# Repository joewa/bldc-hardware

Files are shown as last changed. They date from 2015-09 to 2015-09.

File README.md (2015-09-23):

bldc-hardware
=============



This the Hardware for my open source custom ESC. This is a forked repository from mrkindustries, who made many improvements to my original hardware design.

Here is a BOM on google drive that I try to keep up to date:
https://docs.google.com/spreadsheet/ccc?key=0AnvZ-ouEB058dGpzaDl4MUxNM3NxZ1BzTWNZZ1RhRUE&usp=sharing

Have a look at this post for a tutorial on how to get started:
http://vedder.se/2015/01/vesc-open-source-esc/

VESC Hardware is licensed under the Creative Commons Attribution-ShareAlike 4.0 International License. To view a copy of this license, visit http://creativecommons.org/licenses/by-sa/4.0/.

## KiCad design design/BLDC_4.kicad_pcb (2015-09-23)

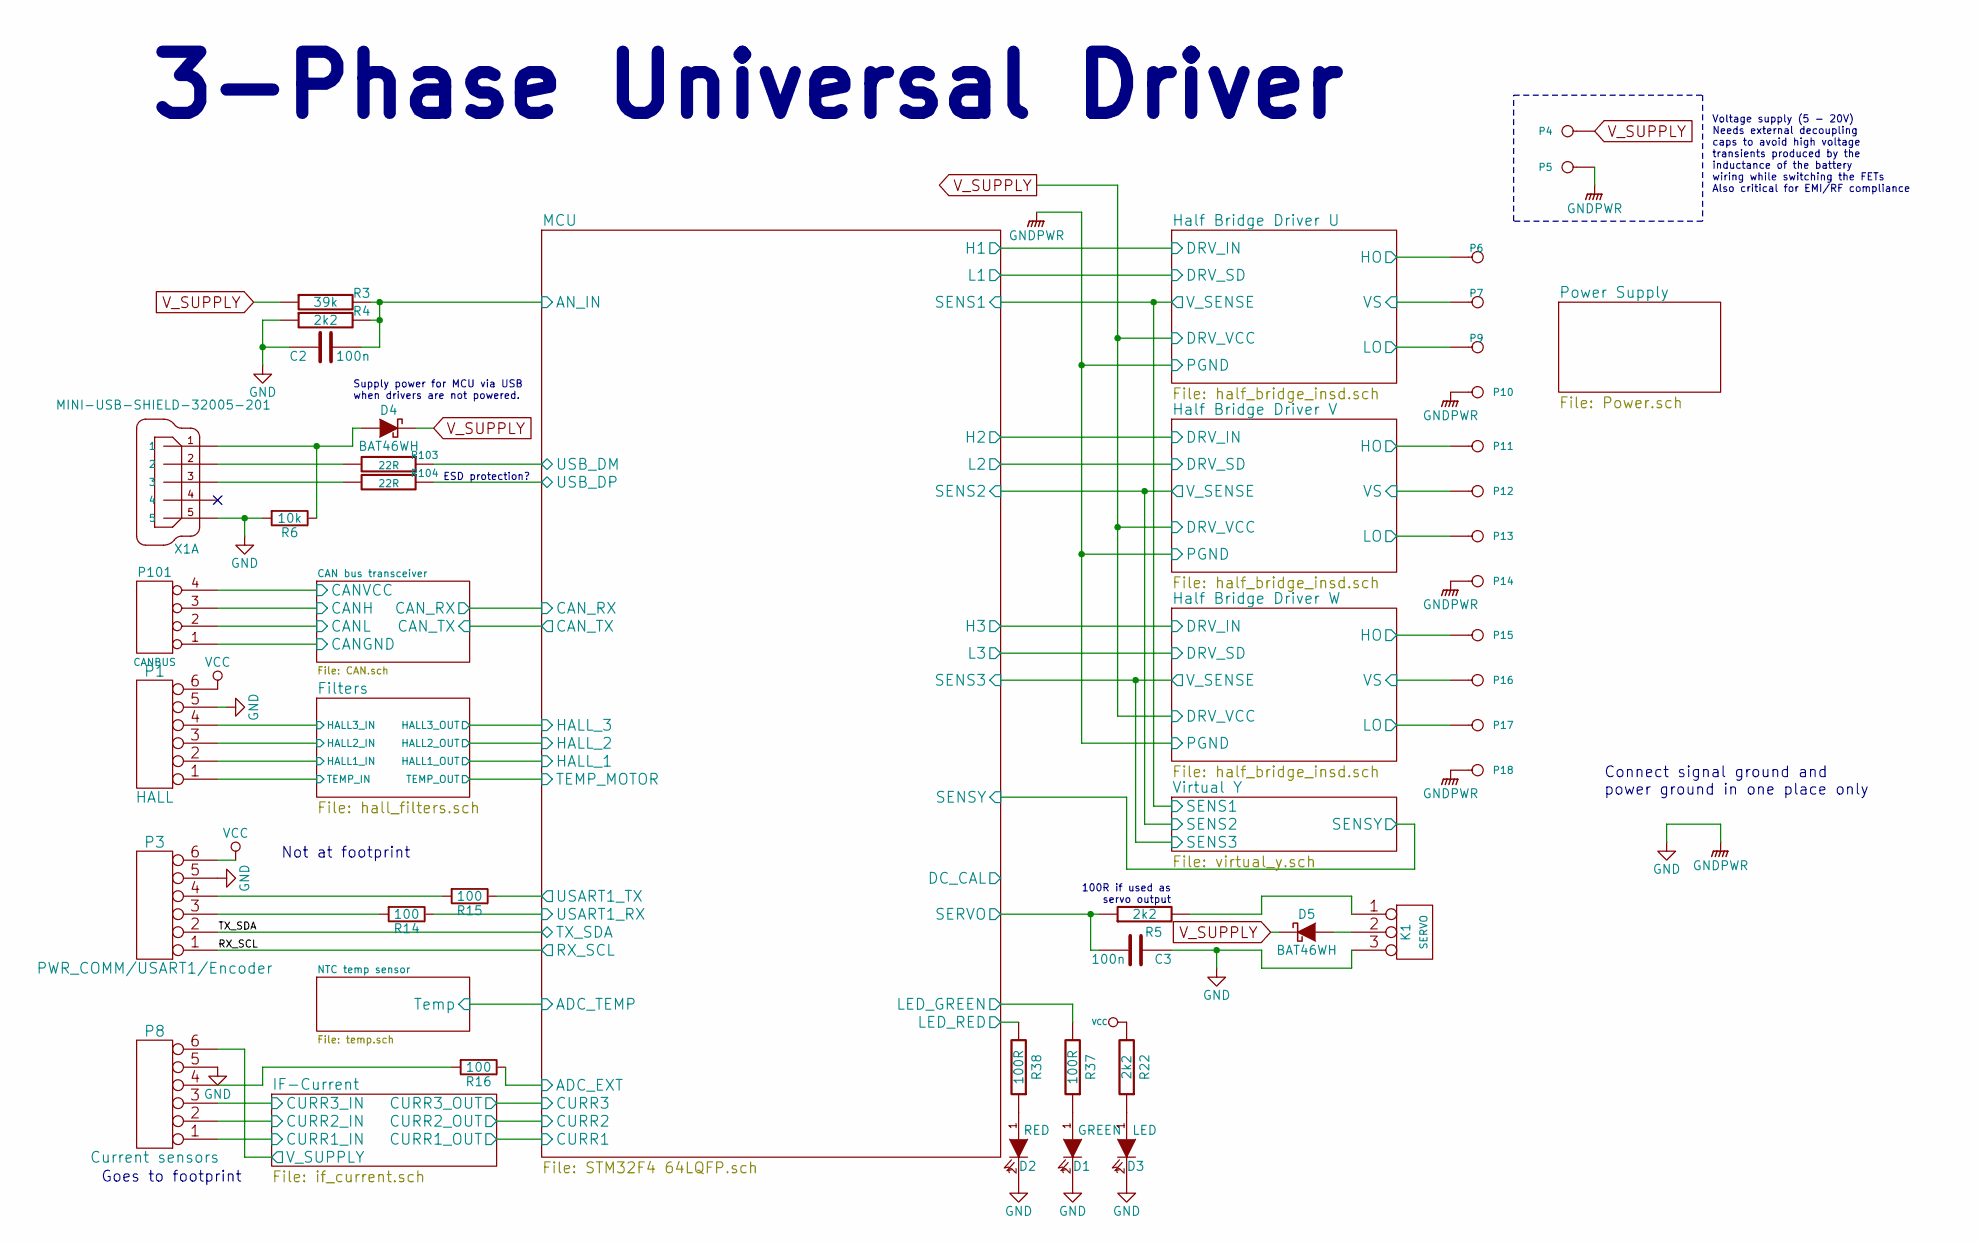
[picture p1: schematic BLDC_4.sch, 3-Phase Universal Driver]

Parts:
C2, C3: 100n; C_0603
D1: GREEN; LED-0603
D2: RED; LED-0603
D3: LED; LED-0603
D4, D5: BAT46WH; SOD-123
K1: SERVO; pinhead-1X03
P1: HALL; MICRO_JST_6
P3: PWR_COMM/USART1/Encoder; MICRO_JST_6
P4: IN+; 1PAD_4x5mm
P5: IN-; 1PAD_4x5mm
P6, P7: CONN_DRV; 1PAD_4x5mm
P8: Current sensors; MICRO_JST_6
P9, P10, P11, P12, P13, P14, P15, P16, P17, P18: CONN_DRV; PAD_DRV
P101: CANBUS; pinhead-1X03
R3: 39k; R_0603_HandSoldering
R4, R5, R22: 2k2; R_0603_HandSoldering
R6: 10k; R_0603
R14, R15, R16: 100; R_0603
R37, R38: 100R; R_0603
R103, R104: 22R; R_0603
X1: MINI-USB-SHIELD-32005-201; con-cypressindustries-32005-201

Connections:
/CAN bus transceiver/CANGND: P101.1; also elsewhere on the board
/CAN bus transceiver/CANH: P101.3; also elsewhere on the board
/CAN bus transceiver/CANL: P101.2; also elsewhere on the board
/Filters/HALL1_IN: P1.2; also elsewhere on the board
/Filters/HALL2_IN: P1.3; also elsewhere on the board
/Filters/HALL3_IN: P1.4; also elsewhere on the board
/Filters/TEMP_IN: P1.1; also elsewhere on the board
/Half Bridge Driver U/HO: P6.1; also elsewhere on the board
/Half Bridge Driver U/LO: P9.1; also elsewhere on the board
/Half Bridge Driver U/VS: P7.1; also elsewhere on the board
/Half Bridge Driver V/HO: P11.1; also elsewhere on the board
/Half Bridge Driver V/LO: P13.1; also elsewhere on the board
/Half Bridge Driver V/VS: P12.1; also elsewhere on the board
/Half Bridge Driver W/HO: P15.1; also elsewhere on the board
/Half Bridge Driver W/LO: P17.1; also elsewhere on the board
/Half Bridge Driver W/VS: P16.1; also elsewhere on the board
/IF-Current/CURR1_IN: P8.1; also elsewhere on the board
/IF-Current/CURR2_IN: P8.2; also elsewhere on the board
/IF-Current/CURR3_IN: P8.3; also elsewhere on the board
/IF-Current/V_SUPPLY: P8.6; also elsewhere on the board
/MCU/ADC_EXT: R16.1; also elsewhere on the board
/MCU/AN_IN: C2.2, R3.2, R4.2; also elsewhere on the board
/MCU/LED_GREEN: R37.2; also elsewhere on the board
/MCU/LED_RED: R38.2; also elsewhere on the board
/MCU/RX_SCL: P3.1; also elsewhere on the board
/MCU/SERVO: C3.2, R5.1; also elsewhere on the board
/MCU/TX_SDA: P3.2; also elsewhere on the board
/MCU/USART1_RX: R14.1; also elsewhere on the board
/MCU/USART1_TX: R15.1; also elsewhere on the board
/MCU/USB_DM: R103.1; also elsewhere on the board
/MCU/USB_DP: R104.1; also elsewhere on the board
GND: C2.1, C3.1, D1.2 (K), D2.2 (K), D3.2 (K), K1.3, P1.5, P3.5, P5.1, P8.5, P10.1, P14.1, P18.1, R4.1, R6.2, X1.5; also elsewhere on the board
unnamed: D1.1 (A), R37.1
unnamed: D2.1 (A), R38.1
unnamed: D3.1 (A), R22.1
unnamed: D4.2 (A), R6.1, X1.1
unnamed: D5.2 (A), K1.2 (PM)
unnamed: K1.1, R5.2
unnamed: P3.3, R14.2
unnamed: P3.4, R15.2
unnamed: P8.4, R16.2
unnamed: R103.2, X1.2
unnamed: R104.2, X1.3
VCC: P1.6, P3.6, R22.2; also elsewhere on the board
V_SUPPLY: D4.1 (K), D5.1 (K), P4.1, R3.1; also elsewhere on the board

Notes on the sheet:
100R if used as servo output
Supply power for MCU via USB when drivers are not powered.
ESD protection?
3-Phase Universal Driver
Voltage supply (5 - 20V) Needs external decoupling caps to avoid high voltage transients produced by the inductance of the battery wiring while switching the FETs Also critical for EMI/RF compliance
Connect signal ground and power ground in one place only
Not at footprint
Goes to footprint

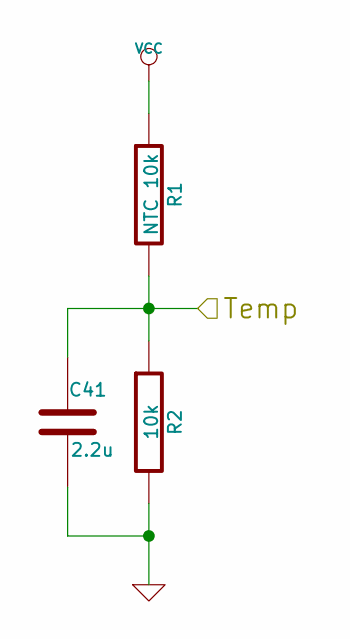
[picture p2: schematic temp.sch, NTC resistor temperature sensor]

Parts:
C41: 2.2u; C_0603
R1: NTC 10k; R_0603_HandSoldering
R2: 10k; R_0603_HandSoldering

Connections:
/MCU/ADC_TEMP: C41.1, R1.2, R2.1; also elsewhere on the board
GND: C41.2, R2.2; also elsewhere on the board
VCC: R1.1; also elsewhere on the board

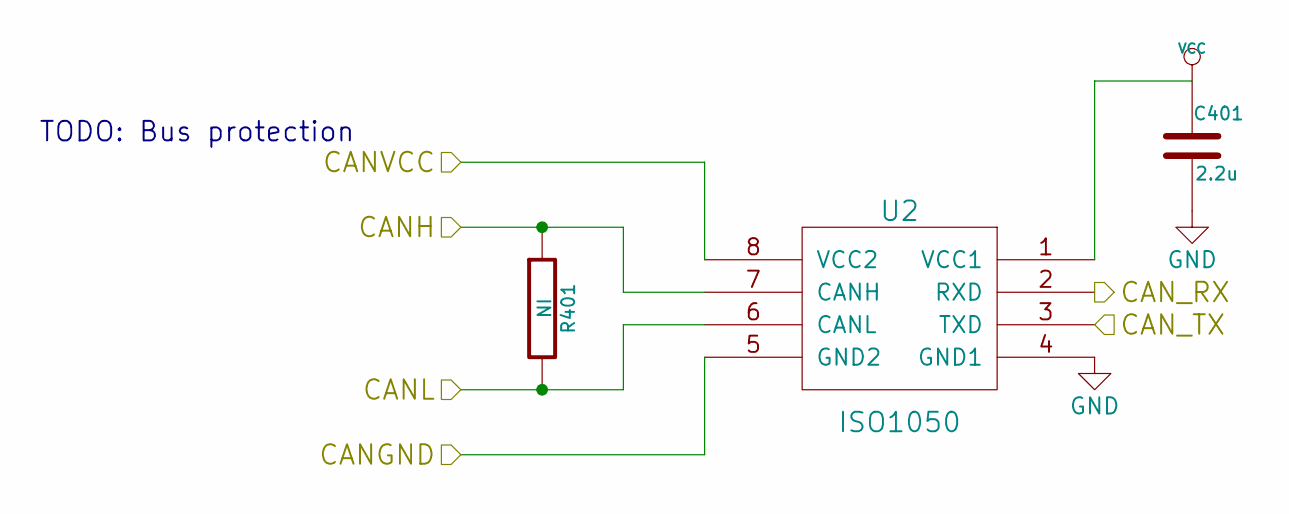
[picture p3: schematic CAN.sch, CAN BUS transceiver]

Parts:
C401: 2.2u; C_0603
R401: NI; R_0603_HandSoldering
U2: ISO1050; PDSO-G8

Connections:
/CAN bus transceiver/CANGND: U2.5 (GND2); also elsewhere on the board
/CAN bus transceiver/CANH: R401.1, U2.7 (CANH); also elsewhere on the board
/CAN bus transceiver/CANL: R401.2, U2.6 (CANL); also elsewhere on the board
/CAN bus transceiver/CAN_RX: U2.2 (RXD); also elsewhere on the board
/CAN bus transceiver/CAN_TX: U2.3 (TXD); also elsewhere on the board
GND: C401.2, U2.4 (GND1); also elsewhere on the board
VCC: C401.1, U2.1 (VCC1); also elsewhere on the board

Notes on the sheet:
TODO: Bus protection

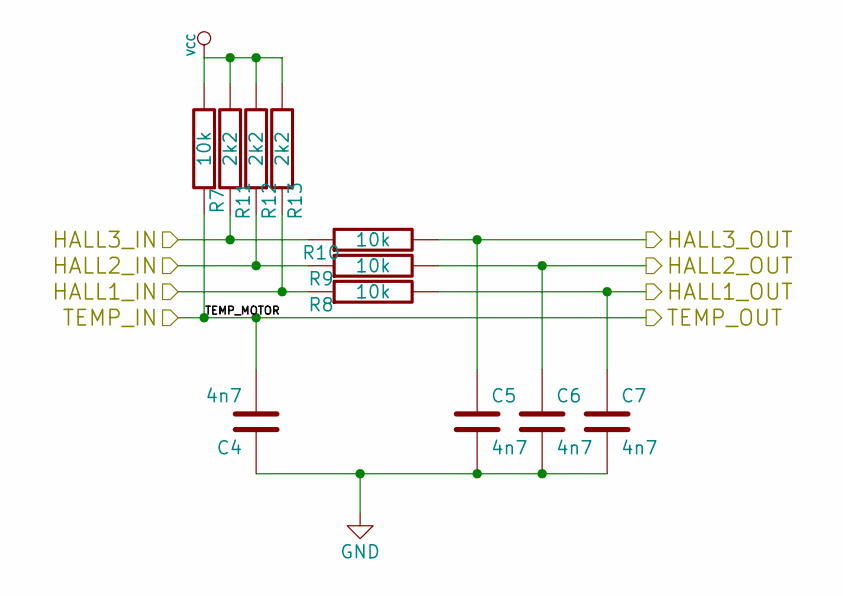
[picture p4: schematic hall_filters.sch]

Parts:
C4, C5, C6, C7: 4n7; C_0603
R7, R8, R9, R10: 10k; R_0603
R11, R12, R13: 2k2; R_0603

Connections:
/Filters/HALL1_IN: R8.1, R13.1; also elsewhere on the board
/Filters/HALL1_OUT: C7.1, R8.2; also elsewhere on the board
/Filters/HALL2_IN: R9.1, R12.1; also elsewhere on the board
/Filters/HALL2_OUT: C6.1, R9.2; also elsewhere on the board
/Filters/HALL3_IN: R10.1, R11.1; also elsewhere on the board
/Filters/HALL3_OUT: C5.1, R10.2; also elsewhere on the board
/Filters/TEMP_IN: C4.2, R7.1; also elsewhere on the board
GND: C4.1, C5.2, C6.2, C7.2; also elsewhere on the board
VCC: R7.2, R11.2, R12.2, R13.2; also elsewhere on the board

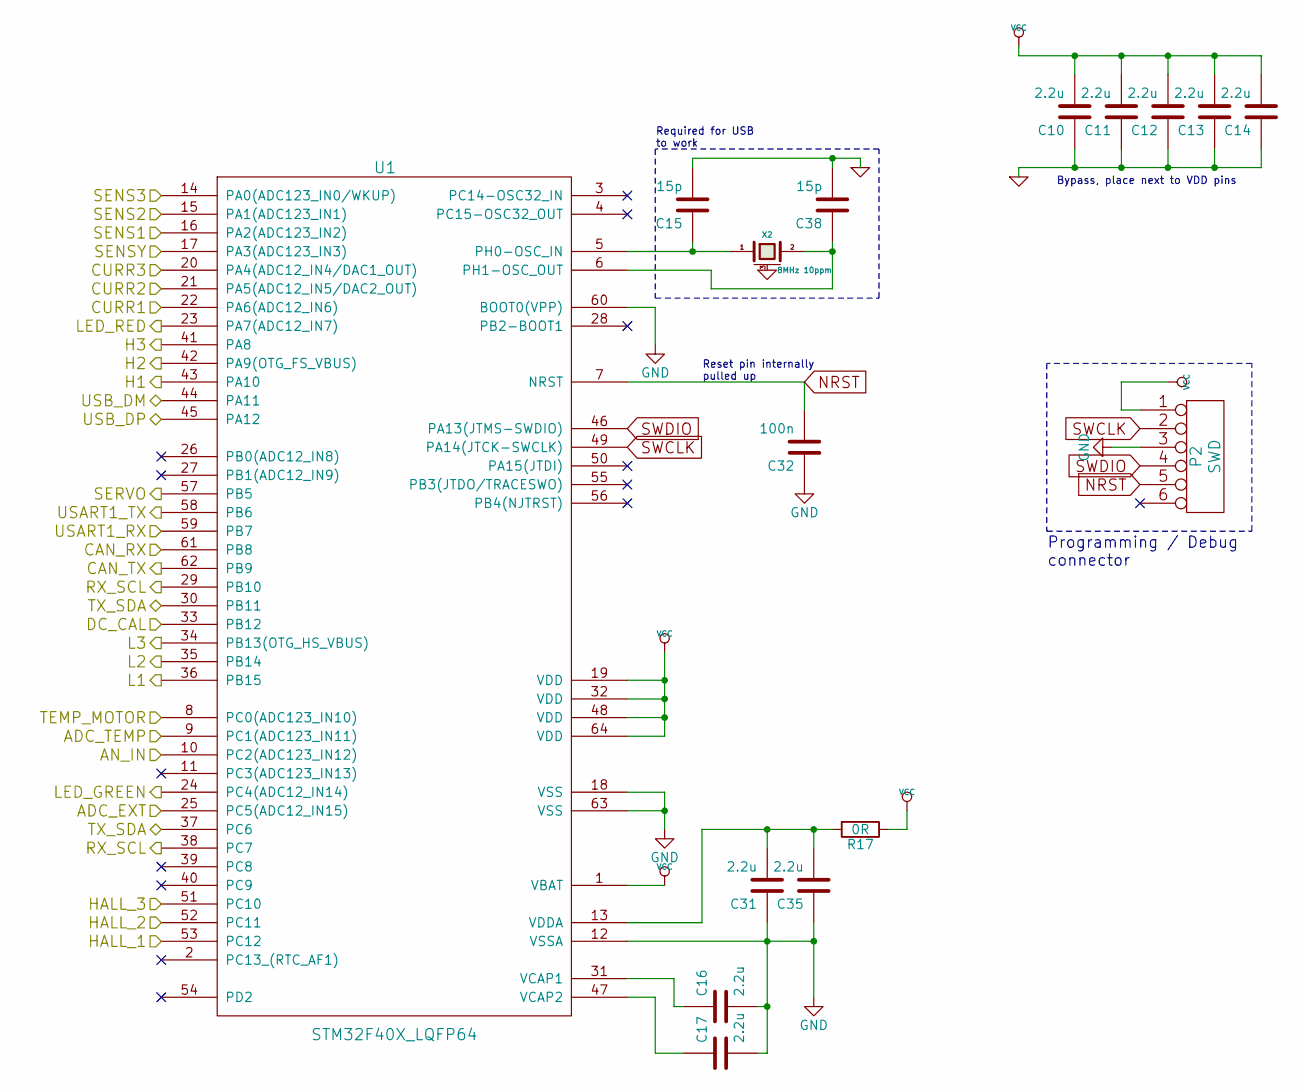
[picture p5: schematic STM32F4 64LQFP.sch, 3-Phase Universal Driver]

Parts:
C10, C11, C12, C13, C14, C16, C17, C31, C35: 2.2u; C_0603
C15, C38: 15p; C_0603
C32: 100n; C_0603
P2: SWD; MICRO_JST_6
R17: 0R; R_0603_HandSoldering
U1: STM32F40X_LQFP64; lqfp64_pad_mod
X2: 8MHz 10ppm; Crystal_5x3mm; mfg# ABM3B-8.0-10-1UT

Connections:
/CAN bus transceiver/CAN_RX: U1.61 (PB8); also elsewhere on the board
/CAN bus transceiver/CAN_TX: U1.62 (PB9); also elsewhere on the board
/Filters/HALL1_OUT: U1.53 (PC12); also elsewhere on the board
/Filters/HALL2_OUT: U1.52 (PC11); also elsewhere on the board
/Filters/HALL3_OUT: U1.51 (PC10); also elsewhere on the board
/Filters/TEMP_IN: U1.8 (PC0(ADC123_IN10)); also elsewhere on the board
/Half Bridge Driver U/DRV_IN: U1.43 (PA10); also elsewhere on the board
/Half Bridge Driver U/DRV_SD: U1.36 (PB15); also elsewhere on the board
/Half Bridge Driver V/DRV_IN: U1.42 (PA9(OTG_FS_VBUS)); also elsewhere on the board
/Half Bridge Driver V/DRV_SD: U1.35 (PB14); also elsewhere on the board
/Half Bridge Driver W/DRV_IN: U1.41 (PA8); also elsewhere on the board
/Half Bridge Driver W/DRV_SD: U1.34 (PB13(OTG_HS_VBUS)); also elsewhere on the board
/MCU/ADC_EXT: U1.25 (PC5(ADC12_IN15)); also elsewhere on the board
/MCU/ADC_TEMP: U1.9 (PC1(ADC123_IN11)); also elsewhere on the board
/MCU/AN_IN: U1.10 (PC2(ADC123_IN12)); also elsewhere on the board
/MCU/CURR1: U1.22 (PA6(ADC12_IN6)); also elsewhere on the board
/MCU/CURR2: U1.21 (PA5(ADC12_IN5/DAC2_OUT)); also elsewhere on the board
/MCU/CURR3: U1.20 (PA4(ADC12_IN4/DAC1_OUT)); also elsewhere on the board
/MCU/LED_GREEN: U1.24 (PC4(ADC12_IN14)); also elsewhere on the board
/MCU/LED_RED: U1.23 (PA7(ADC12_IN7)); also elsewhere on the board
/MCU/RX_SCL: U1.29 (PB10), U1.38 (PC7); also elsewhere on the board
/MCU/SENS1: U1.16 (PA2(ADC123_IN2)); also elsewhere on the board
/MCU/SENS2: U1.15 (PA1(ADC123_IN1)); also elsewhere on the board
/MCU/SENS3: U1.14 (PA0(ADC123_IN0/WKUP)); also elsewhere on the board
/MCU/SENSY: U1.17 (PA3(ADC123_IN3)); also elsewhere on the board
/MCU/SERVO: U1.57 (PB5); also elsewhere on the board
/MCU/TX_SDA: U1.30 (PB11), U1.37 (PC6); also elsewhere on the board
/MCU/USART1_RX: U1.59 (PB7); also elsewhere on the board
/MCU/USART1_TX: U1.58 (PB6); also elsewhere on the board
/MCU/USB_DM: U1.44 (PA11); also elsewhere on the board
/MCU/USB_DP: U1.45 (PA12); also elsewhere on the board
GND: C10.1, C11.1, C12.1, C13.1, C14.1, C15.2, C16.2, C17.2, C31.1, C32.1, C35.1, C38.2, P2.3, U1.12 (VSSA), U1.18 (VSS), U1.60 (BOOT0(VPP)), U1.63 (VSS), X2.3 (case); also elsewhere on the board
NRST: C32.2, P2.5, U1.7 (NRST)
unnamed: C15.1, U1.5 (PH0-OSC_IN), X2.1
unnamed: C16.1, U1.31 (VCAP1)
unnamed: C17.1, U1.47 (VCAP2)
unnamed: C31.2, C35.2, R17.2, U1.13 (VDDA)
unnamed: C38.1, U1.6 (PH1-OSC_OUT), X2.2
SWCLK: P2.2, U1.49 (PA14(JTCK-SWCLK))
SWDIO: P2.4, U1.46 (PA13(JTMS-SWDIO))
VCC: C10.2, C11.2, C12.2, C13.2, C14.2, P2.1, R17.1, U1.1 (VBAT), U1.19 (VDD), U1.32 (VDD), U1.48 (VDD), U1.64 (VDD); also elsewhere on the board

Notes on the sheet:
Programming / Debug connector
Reset pin internally pulled up
Required for USB to work
Bypass, place next to VDD pins

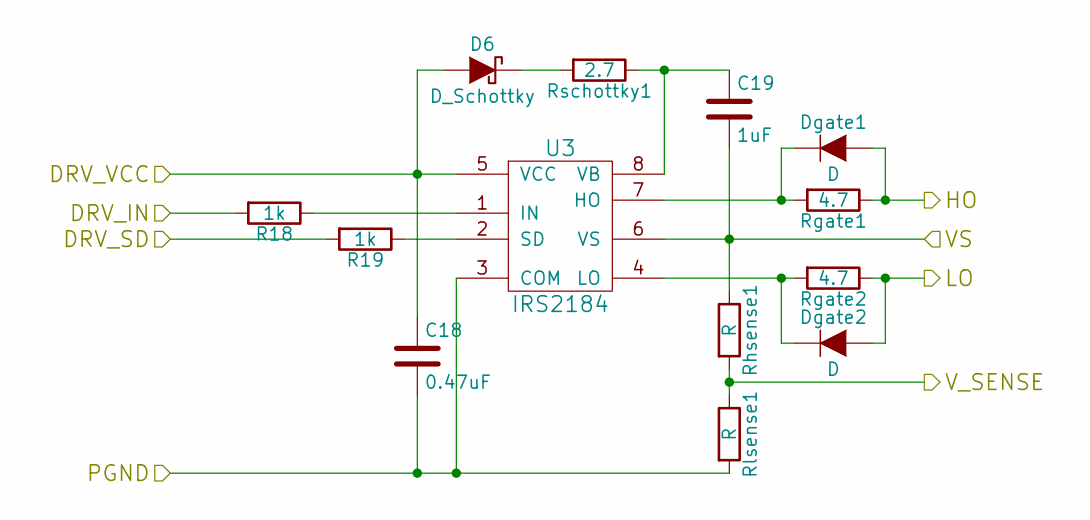
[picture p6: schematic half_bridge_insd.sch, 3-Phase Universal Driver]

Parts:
C18: 0.47uF; C_0805_HandSoldering
C19: 1uF; C_1210_HandSoldering
D6: D_Schottky; DO-214AC_SOD-123
Dgate1, Dgate2: D; SOD-123
R18, R19: 1k; R_0603
Rgate1, Rgate2: 4.7; R_0805_HandSoldering
Rhsense1: R; R_0805_HandSoldering
Rlsense1: R; R_0603_HandSoldering
Rschottky1: 2.7; R_0805_HandSoldering
U3: IRS2184; SOIC-8_3.9x4.9mm_Pitch1.27mm

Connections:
/Half Bridge Driver U/DRV_IN: R18.2; also elsewhere on the board
/Half Bridge Driver U/DRV_SD: R19.2; also elsewhere on the board
/Half Bridge Driver U/HO: Dgate1.2 (A), Rgate1.1; also elsewhere on the board
/Half Bridge Driver U/LO: Dgate2.2 (A), Rgate2.1; also elsewhere on the board
/Half Bridge Driver U/VS: C19.2, Rhsense1.1, U3.6 (VS); also elsewhere on the board
/MCU/SENS1: Rhsense1.2, Rlsense1.1; also elsewhere on the board
GND: C18.2, Rlsense1.2, U3.3 (COM); also elsewhere on the board
unnamed: C19.1, Rschottky1.1, U3.8 (VB)
unnamed: D6.1 (K), Rschottky1.2
unnamed: Dgate1.1 (K), Rgate1.2, U3.7 (HO)
unnamed: Dgate2.1 (K), Rgate2.2, U3.4 (LO)
unnamed: R18.1, U3.1 (IN)
unnamed: R19.1, U3.2 (SD)
V_SUPPLY: C18.1, D6.2 (A), U3.5 (VCC); also elsewhere on the board

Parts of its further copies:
C20, C22: 0.47uF; C_0805_HandSoldering
C21, C23: 1uF; C_1210_HandSoldering
D7, D8: D_Schottky; DO-214AC_SOD-123
Dgate3, Dgate4, Dgate5, Dgate6: D; SOD-123
R20, R21, R23, R24: 1k; R_0603
Rgate3, Rgate4, Rgate5, Rgate6: 4.7; R_0805_HandSoldering
Rhsense2, Rhsense3: R; R_0805_HandSoldering
Rlsense2, Rlsense3: R; R_0603_HandSoldering
Rschottky2, Rschottky3: 2.7; R_0805_HandSoldering
U4, U5: IRS2184; SOIC-8_3.9x4.9mm_Pitch1.27mm

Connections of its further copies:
/Half Bridge Driver V/DRV_IN: R20.2; also elsewhere on the board
/Half Bridge Driver V/DRV_SD: R21.2; also elsewhere on the board
/Half Bridge Driver V/HO: Dgate3.2 (A), Rgate3.1; also elsewhere on the board
/Half Bridge Driver V/LO: Dgate4.2 (A), Rgate4.1; also elsewhere on the board
/Half Bridge Driver V/VS: C21.2, Rhsense2.1, U4.6 (VS); also elsewhere on the board
/Half Bridge Driver W/DRV_IN: R23.2; also elsewhere on the board
/Half Bridge Driver W/DRV_SD: R24.2; also elsewhere on the board
/Half Bridge Driver W/HO: Dgate5.2 (A), Rgate5.1; also elsewhere on the board
/Half Bridge Driver W/LO: Dgate6.2 (A), Rgate6.1; also elsewhere on the board
/Half Bridge Driver W/VS: C23.2, Rhsense3.1, U5.6 (VS); also elsewhere on the board
/MCU/SENS2: Rhsense2.2, Rlsense2.1; also elsewhere on the board
/MCU/SENS3: Rhsense3.2, Rlsense3.1; also elsewhere on the board
GND: C20.2, C22.2, Rlsense2.2, Rlsense3.2, U4.3 (COM), U5.3 (COM); also elsewhere on the board
unnamed: C21.1, Rschottky2.1, U4.8 (VB)
unnamed: C23.1, Rschottky3.1, U5.8 (VB)
unnamed: D7.1 (K), Rschottky2.2
unnamed: D8.1 (K), Rschottky3.2
unnamed: Dgate3.1 (K), Rgate3.2, U4.7 (HO)
unnamed: Dgate4.1 (K), Rgate4.2, U4.4 (LO)
unnamed: Dgate5.1 (K), Rgate5.2, U5.7 (HO)
unnamed: Dgate6.1 (K), Rgate6.2, U5.4 (LO)
unnamed: R20.1, U4.1 (IN)
unnamed: R21.1, U4.2 (SD)
unnamed: R23.1, U5.1 (IN)
unnamed: R24.1, U5.2 (SD)
V_SUPPLY: C20.1, C22.1, D7.2 (A), D8.2 (A), U4.5 (VCC), U5.5 (VCC); also elsewhere on the board

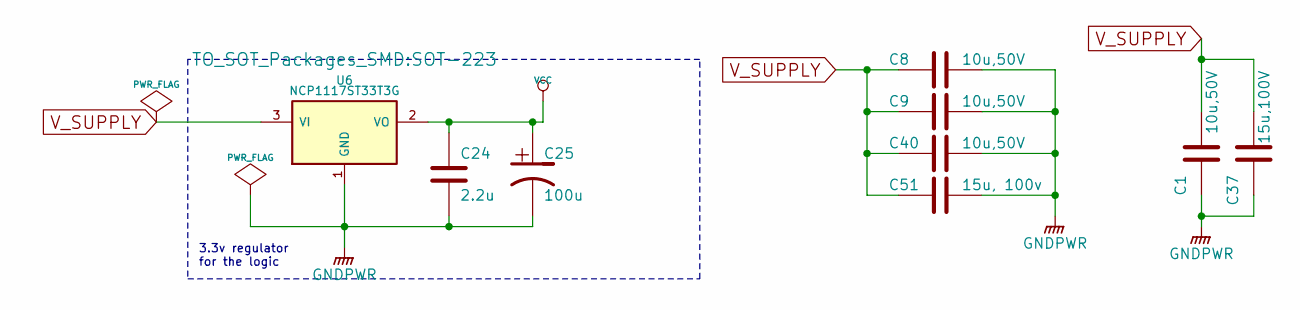
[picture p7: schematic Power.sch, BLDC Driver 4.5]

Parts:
C1, C8, C9, C40: 10u,50V; C_1206
C24: 2.2u; C_0603
C25: 100u; TantalC_SizeB_EIA-3528_HandSoldering
C37: 15u,100V; C_2220
C51: 15u, 100v; C_2220
U6: NCP1117ST33T3G; SOT-223

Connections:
GND: C1.1, C8.1, C9.1, C24.2, C25.2, C37.1, C40.1, C51.1, U6.1 (GND); also elsewhere on the board
VCC: C24.1, C25.1, U6.2 (VO); also elsewhere on the board
V_SUPPLY: C1.2, C8.2, C9.2, C37.2, C40.2, C51.2, U6.3 (VI); also elsewhere on the board

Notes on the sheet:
3.3v regulator for the logic

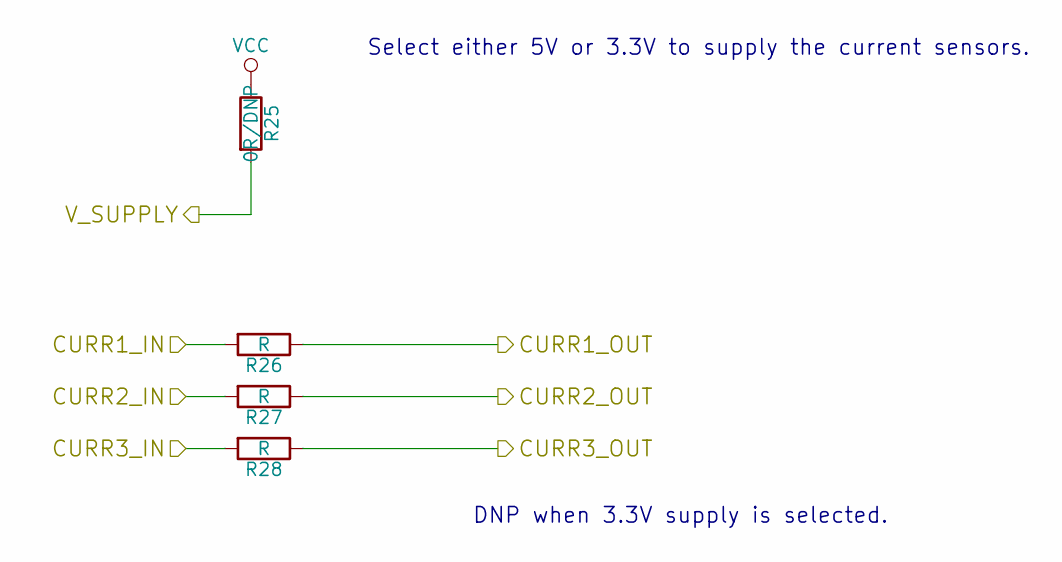
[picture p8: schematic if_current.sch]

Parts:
R25: 0R/DNP; R_0603_HandSoldering
R26, R27, R28: R; R_0603

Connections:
/IF-Current/CURR1_IN: R26.2; also elsewhere on the board
/IF-Current/CURR2_IN: R27.2; also elsewhere on the board
/IF-Current/CURR3_IN: R28.2; also elsewhere on the board
/IF-Current/V_SUPPLY: R25.2; also elsewhere on the board
/MCU/CURR1: R26.1; also elsewhere on the board
/MCU/CURR2: R27.1; also elsewhere on the board
/MCU/CURR3: R28.1; also elsewhere on the board
VCC: R25.1; also elsewhere on the board

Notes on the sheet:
Select either 5V or 3.3V to supply the current sensors.
DNP when 3.3V supply is selected.

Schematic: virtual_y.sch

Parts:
R29, R30, R31: R; R_0603_HandSoldering

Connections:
/MCU/SENS1: R29.2; also elsewhere on the board
/MCU/SENS2: R30.2; also elsewhere on the board
/MCU/SENS3: R31.2; also elsewhere on the board
/MCU/SENSY: R29.1, R30.1, R31.1; also elsewhere on the board

Board: 2 copper layers, 127 parts (0 on the bottom side), 90 nets, no tracks yet.

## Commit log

2015-08-22 Saved project with more recent version of KiCad. Added IRS2184 half bridge driver to BLDC_4_cache.lib
    [BLDC_4.sch, CAN.sch, Power.sch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]
2015-08-24 Draft IRS2184 bootstrap driver circuit.
    [BLDC_4.sch, CAN.sch, Power.sch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]
2015-08-24 Added new drivers and removed the big old one.
    [BLDC_4.sch, CAN.sch, Power.sch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]
2015-08-26 Removed 5V power level. Integrated isolated CAN bus driver.
    [BLDC_4.sch, CAN.sch, Power.sch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]
2015-08-27 First complete draft of the schematics.
    [BLDC_4.sch, CAN.sch, Power.sch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]
2015-08-27 Assigned some footprints.
    [BLDC_4.sch, CAN.sch, Power.sch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]
2015-09-02 Added footprint that fits SOD-123 and DO-214AC bootstrap diodes.
    [Power.sch, half_bridge_insd.sch]
2015-09-04 Selected footprints
    [BLDC_4.sch, CAN.sch, Power.sch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]
2015-09-05 Generated first netlist and started working with pcbnew.
    [BLDC_4.kicad_pcb, Power.sch]
2015-09-23 Arranged some parts.
    [BLDC_4.kicad_pcb]
2015-12-29 Agreed programming connector with esden.
    [Power.sch, STM32F4 64LQFP.sch]
